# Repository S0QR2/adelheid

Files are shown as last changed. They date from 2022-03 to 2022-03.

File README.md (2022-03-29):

# SANNY - The ISO Version of 𝕬𝖉𝖊𝖑𝖍𝖊𝖎𝖉

Sanny is a 75% Alice-like keyboard with fixed ISO Layout.



It's a fork of FateNozomi's Arisu files: [Arisu PCB](https://github.com/FateNozomi/arisu-pcb) &amp; [Arisu case](https://github.com/FateNozomi/arisu-case)

This repository includes files for:

- the Sanny PCB &rarr; [README.md](./pcb/README.md)
- a layered case &rarr; [README.md](./case/README.md)
- a wrist rest is available in the original Respository &rarr;

## Changes in this fork

added 2u backspace, ISO Enter and NUBS

## Layout

A spaced 75% layout on top of the Alice/Arisu-layout with an ISO enter.

## Firmware

A via compatible json file which is compatible with the adelheid-via firmware is also included in this repo.  
In the QMK repository: <https://github.com/qmk/qmk_firmware/tree/master/keyboards/adelheid>  
And the online configurator: https://config.qmk.fm/#/adelheid/LAYOUT

A VIAL Firmware Version with ISO Layout: https://github.com/S0QR2/adelheid/blob/iso/sanny_vial.hex

VIAL_Dark

## Miscellaneous

Considerations when building: https://github.com/S0QR2/adelheid/blob/iso/IMAGES.md

Use at your own Risk

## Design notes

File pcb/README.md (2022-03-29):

# Sanny - PCB

Top  

Bottom

The PCB for the Sanny was designed using KiCAD on top of the Arisu PCB files.

## Changes compared to the Arisu PCB

- [x] Added a spaced function row
- [x] Added footprint for stepped caps lock key
- [x] Changed the micro USB port to a tht mini USB port
- [x] Added single color underglow and key lighting

## Changes compared to the Adelheid PCB

- [x] Added 2U Backspace 
- [x] Added ISO Enter
- [x] Added KC_NUBS  

## FateNozomi's Arisu description

>アリス PCB designed using KiCad. The layout is inspired by Lyn's EM7 and TGR Alice with some modification of my own.
>
> Key differences:
>
> - I removed the extra [B] key on the right half and shifted the [NM,.?] row > to the left by 0.25U.
> - Shifted the 3 keys to the right and added arrow keys.
> - Tweaked the bottom so that the 1.5U keys doesn't protrude out a little.
>
> Shifting the [NM,.?] row to the left by 0.25U required quite some work on the arrangement of keys for the right half.  
> As a result, this does not give the same typing experience as Lyn's EM7 and TGR Alice.
> Lyn's EM7 and TGR Alice uses the home row as the center point to vertically align both halves while I used the number row instead.  
> Due to the nature of staggered keyboards, aligning using the number row resulted in the home row not being aligned.

The Adelheid inherits these changes from the Arisu.

## KiCAD libraries in use

- [ai03/MX_Only](https://github.com/ai03-2725/MX_Alps_Hybrid/tree/master/MX_Only.pretty) for MX switch footprints (local copy in `./lib/`)
- [Keebio-Parts](https://github.com/keebio/Keebio-Parts.pretty) for mini USB port footprint

## Parts list

### SMD

All SMD parts are listed in the [BOM](./adelheid.gerber/adelheid.csv) with their corresponding value, label and LCSC number.  
If you opt in for LED backlighting/underglow please make sure to use the correct resistor size for your LEDs in order for your PCB to function correctly. See [here](#backlighting) for led resistor estimations.

### THT

- 82x MX switches
- 1x through-hole mini USB 2.0 port (MX-54819-0519)
- (optional) 82x 3mm single color LEDs

## Backlighting

To calculate what resistors you'll need you can use my [backlight calculator spreadsheet](./backlight.ods) to calculate the estimated total power draw. Enter your LED specifications and either enter the desired current per LED or enter the resistor size which you are planning on using. The spreadsheet should calculate the total power draw and compare it to the allowed power draw of USB 2.0 (500 mA). *I'm no electrical engineer so please be cautious.*

<!-- ![underglow](https://gist.githubusercontent.com/floookay/7bf6511a8d84804d32de4d7bbe3bd0fb/raw/4545813142abf2e65902b7caca10f7a3b39ebaed/underglow.jpg) -->
<!-- ![full backlight](https://gist.githubusercontent.com/floookay/7bf6511a8d84804d32de4d7bbe3bd0fb/raw/9e10a12793ed65a09f529caf7a6c52b8ec96cc22/backlight_full.jpg) -->

## **Disclaimer**

Please use these files at your own risk.

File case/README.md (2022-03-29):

# Sanny - Case

## Lasercutable Layered Case

Case in Layers

Space inside the Top Layers is perfectly suited for printing something inside like a Plate Support Fork.

Support Fork

https://github.com/S0QR2/adelheid/blob/iso/case/lasercut-layers/hipro_layers_addon_iso_forks.dxf

[more information here](./lasercut-layers/README.md)

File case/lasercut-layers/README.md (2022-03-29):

# Lasercutable Layered Case



The case is kept similarly to the Arisu case:

- sandwich mount
- 6 layers of 3mm material (plus 2 feet layers for angle)
- 
## Assembly parts list

HiPro (LoPro)

- 12x (4x) 12mm M 2.5 screws
- 4x (12x) 4mm M 2.5 screws
- 8x 5mm M 2.5 standoffs
- 4+ self-adhesive anti slip feet (8x3)

## Miscellaneous

> How do I get a layered case?

For a low profile case: Download the `lopro.dxf` file and upload it to a laser cutting service.  
For a high profile case: Download both the `lopro.dxf` and the `hipro_addon.dxf` files and upload both to a laser cutting service.  
Depending on the service you choose you might be able to save some money if you move the parts around so they fit in a better sheet size.

> How do I edit the case files?

If you just want to rearrange the layers I recommend using Inkscape to move the pieces to the desired positions.  
I altered the original files by importing them into Fusion 360, so I included these files for you to work on as well.

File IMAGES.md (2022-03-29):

# Sanny - Images

## Finished Keyboard



Build with clear plate 3mm thickness. If you experience that switches get pushed out from the plate some felt pads can help keep the distance between PCB and Plate.



Felt pads are not visible with keycaps. If you dont want them visible at all, you might opt for an opaque palte.



Half clear and half opaque case can give a nice effect with the underglow



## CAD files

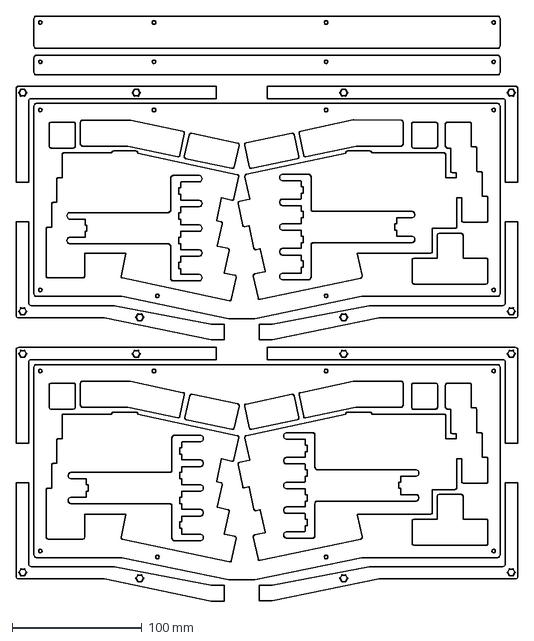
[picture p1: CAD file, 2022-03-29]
case/lasercut-layers/hipro_layers_addon_iso_forks.dxf
386.2 x 450.4 mm
